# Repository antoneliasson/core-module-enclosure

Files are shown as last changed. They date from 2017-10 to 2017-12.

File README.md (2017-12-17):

A snap-together enclosure for Bigclown's Core Module
====================================================

License
-------

With the exception of core-module.stl, which is derived from a model that was created by Bigclown Labs, all the files in this repository are GPL-3 licensed.

    Copyright (C) 2017  Anton Eliasson

    This program is free software: you can redistribute it and/or modify
    it under the terms of the GNU General Public License as published by
    the Free Software Foundation, either version 3 of the License, or
    (at your option) any later version.

    This program is distributed in the hope that it will be useful,
    but WITHOUT ANY WARRANTY; without even the implied warranty of
    MERCHANTABILITY or FITNESS FOR A PARTICULAR PURPOSE.  See the
    GNU General Public License for more details.

    You should have received a copy of the GNU General Public License
    along with this program. If not, see <http://www.gnu.org/licenses/>.

Errata
------

* The cutout for the USB connector is *just* big enough, making it somewhat
  difficult to insert the core module. Should make it slightly taller.
* Next time, separate WallThickness and FloorThickness even if they are the
  same. Should make the code more readable by being more clear what is being
  referred to.
* Make the snaps wider
* Simplify snaps

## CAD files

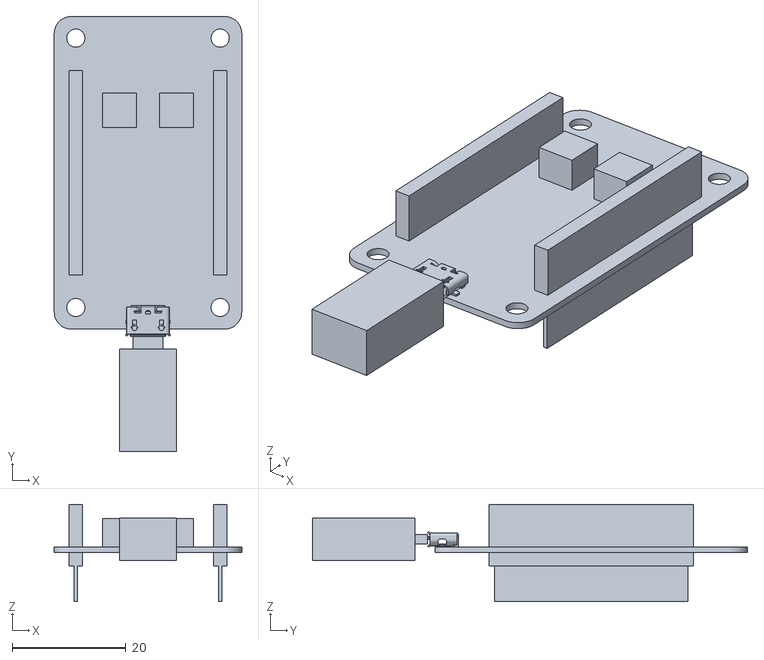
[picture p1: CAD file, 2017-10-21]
core-module.stl
33.0 x 76.5 x 17.1

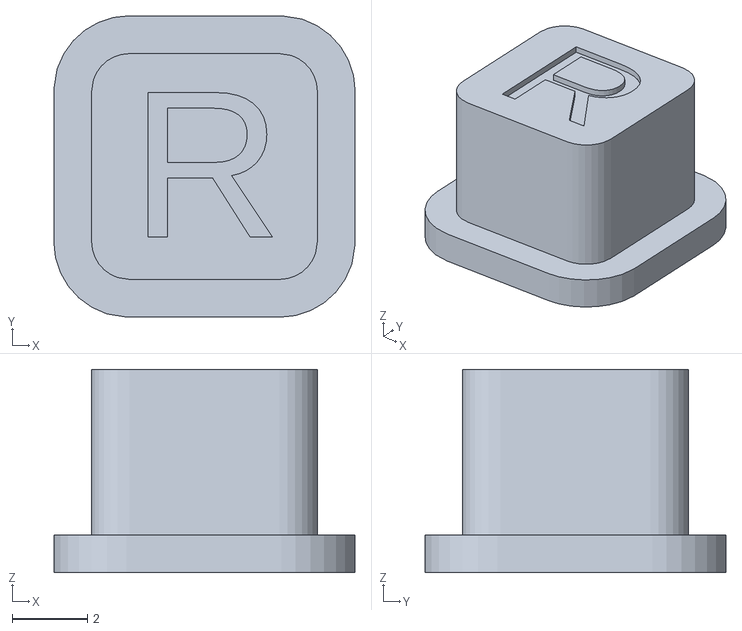
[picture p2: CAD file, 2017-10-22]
export/button R.stl
8.00 x 8.00 x 5.40

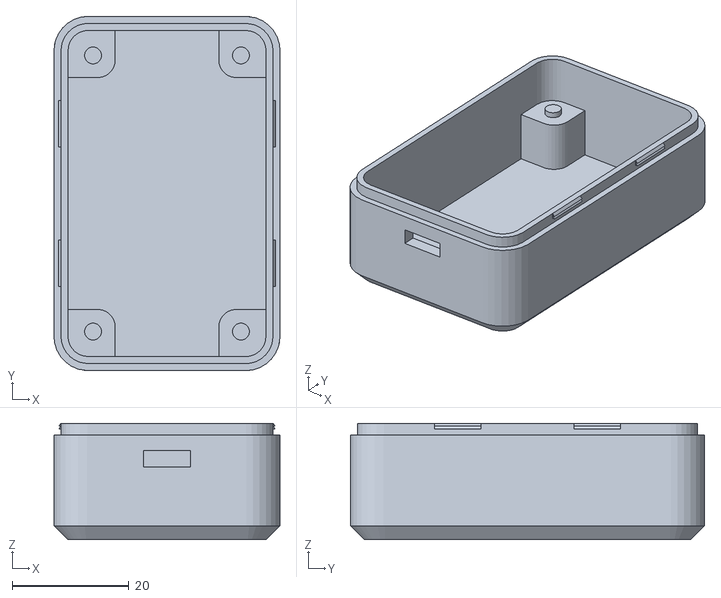
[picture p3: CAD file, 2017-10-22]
export/bottom.stl
38.8 x 60.8 x 20.0

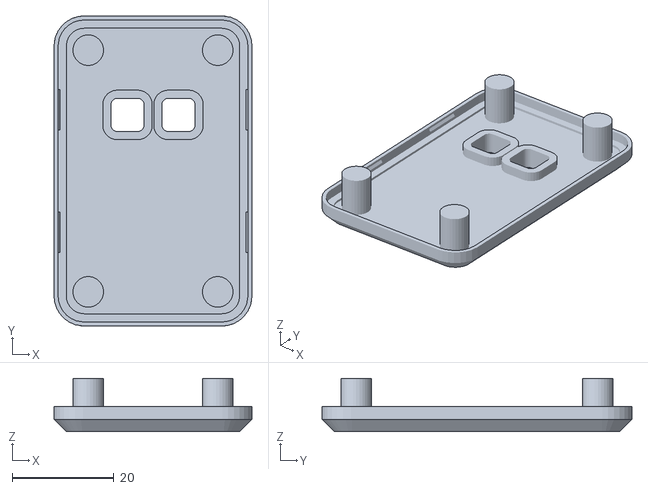
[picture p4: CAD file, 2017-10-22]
export/top.stl
38.8 x 60.8 x 10.4

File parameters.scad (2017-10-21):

WallClearance = 0.5;
WallThickness = 2.4;

pcbw = 33;
pcbl = 55;
pcbt = 1;

PCBHoleR = 1.6;
PCBHoleEdgeDst = 2.2;

BottomHeaderHeight=8.6;
TopHeaderHeight=7.5; // TODO actually measured to 7.70

TightFit = 0.15;
LooseFit = 0.25;

flangeHeight = 2;
flangeW = 1.2;
outerFlangeW = 0.8;

snapH = 0.5;
snapD = 0.4;

buttonW = 6; // TODO merge?
PCBButtonW = 6;
PCBButtonH = 5;

buttonFlange = 1; // W & H
buttonR = 1;

epsilon = 0.001;

$fs=1;

module pcb() {
	rrect4(pcbw, pcbl, 3);
}

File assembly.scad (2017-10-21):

include <parameters.scad>

use <bottom.scad>
use <button.scad>
use <top.scad>

//projection(cut=true) translate([0, 0, 12]) rotate([90, 0, 0])
{
color("firebrick") import("core-module.stl");

render() translate([0, 0, -(BottomHeaderHeight+WallClearance+WallThickness)]) Bottom();

render() translate([0, 0, 0]) translate([0, 0, pcbt+TopHeaderHeight+WallClearance+WallThickness])
	rotate([0, 180, 0]) Top();

render() translate([2+PCBButtonW/2, 8+PCBButtonW/2, pcbt+PCBButtonH]) Button("B");
render() translate([-(2+PCBButtonW/2), 8+PCBButtonW/2, pcbt+PCBButtonH]) Button("R");
}

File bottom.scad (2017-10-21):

use <se/antoneliasson/operations.scad>
use <se/antoneliasson/shapes.scad>

include <parameters.scad>

module standoff() {
	translate([pcbw/2+WallClearance, pcbl/2+WallClearance, 0]) {
		rotate(180)
			linear_extrude(height=BottomHeaderHeight+WallClearance)
				rsquare1(WallClearance+2*PCBHoleEdgeDst+2*PCBHoleR, 3);
	}
	translate([pcbw/2-PCBHoleEdgeDst-PCBHoleR, pcbl/2-PCBHoleEdgeDst-PCBHoleR, BottomHeaderHeight+WallClearance])
		linear_extrude(height=pcbt) circle(r=PCBHoleR-TightFit);
}

module snap() {
	translate([pcbw/2+WallClearance+flangeW, 16, -snapH])
		rotate([90, 0, 0]) linear_extrude(height=8) triangle(snapD, snapH);
}

module Bottom () {
	// floor
	hull() fourwaymirror() translate([pcbw/2-3, pcbl/2-3, 0])
		cylinder(h=WallThickness, r1=3+WallClearance+WallThickness-WallThickness, r2=3+WallClearance+WallThickness);

	fourwaymirror() translate([0, 0, WallThickness]) standoff();

	// walls
	translate([0, 0, WallThickness]) difference () {
		linear_extrude(height=WallClearance
				+BottomHeaderHeight+pcbt+TopHeaderHeight-flangeHeight)
			difference() {
				offset(delta=WallClearance+WallThickness) pcb();
				offset(delta=WallClearance) pcb();
			}

		// usb cutout
		translate([0, -(pcbl/2+WallThickness+WallClearance), BottomHeaderHeight+WallClearance+pcbt]) linear_extrude(height=2.8)
			translate([-4, 0, 0]) square([8, WallThickness]);
	}
	// flange
	translate([0, 0, WallThickness+WallClearance
			+BottomHeaderHeight+pcbt+TopHeaderHeight-flangeHeight]) {
		linear_extrude(height=flangeHeight)
			difference() {
				offset(delta=WallClearance+flangeW) pcb();
				offset(delta=WallClearance) pcb();
			}
		// snaps
		fourwaymirror() {
			translate([0, 0, flangeHeight]) snap();
			// Add an epsilon distance here to prevent the model from becoming non-manifold
			translate([0, 0, flangeHeight-snapH-epsilon]) snap();
		}
	}
}

render() Bottom();

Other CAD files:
export/button B.stl
button.scad
top.scad

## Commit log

2017-10-21 Import core-module STL model as reference
    Source (V2): http://a360.co/2xV9TUz
    [core-module.stl]
2017-10-21 Project startup; first iteration of bottom part done
    [assembly.scad, bottom.scad, parameters.scad]
2017-10-21 Finish general shape of top part
    [assembly.scad, bottom.scad, parameters.scad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]
2017-10-21 Indentation fix
    [bottom.scad]
2017-10-21 Top: button cutouts
    [parameters.scad, top.scad]
2017-10-21 Create basic button
    [button.scad]
2017-10-21 Place buttons in assembly
    [assembly.scad]
2017-10-21 Bottom: make lower outer corners part of floor instead of walls
    Preparation for chamfered edges.
    [bottom.scad]
2017-10-21 Bottom: Chamfer edges
    [bottom.scad]
2017-10-21 Top: make outer edges part of floor instead of walls
    [top.scad]
2017-10-21 Top: chamfered edges
    [top.scad]
2017-10-21 Fix USB cutout after rearranging floor and walls
    [bottom.scad]
2017-10-21 Increase width of snaps
    [bottom.scad, top.scad]
2017-10-21 Ugly fixup to make all parts properly manifold
    [bottom.scad, parameters.scad]
2017-10-22 Add STL exports
    [bottom.stl, button B.stl, button R.stl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]
